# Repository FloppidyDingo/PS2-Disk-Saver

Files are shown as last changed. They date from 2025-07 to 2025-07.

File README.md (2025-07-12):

# PS2-Disk-Saver

A PS2 Slim mod that fixes an issue where the laser ribbon peels up and scratches your disks

If you are printing from this source, you will need to print one of Laser Guard.stl and one of either Ribbon_Shield_V5.stl or Ribbon_Shield_V5_Screw.stl

Installation instructions here: https://github.com/FloppidyDingo/PS2-Disk-Saver/wiki/Installation-Instructions

You can buy premade kits here: https://www.etsy.com/listing/1260716684/playstation-2-disk-saver-ribbon-shield

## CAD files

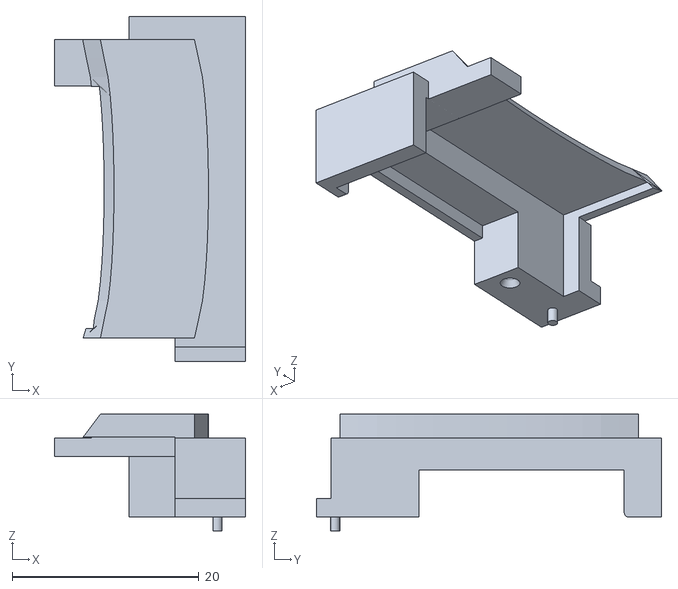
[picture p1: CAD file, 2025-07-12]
PS2 Laser guard.stl
20.5 x 37.0 x 12.5

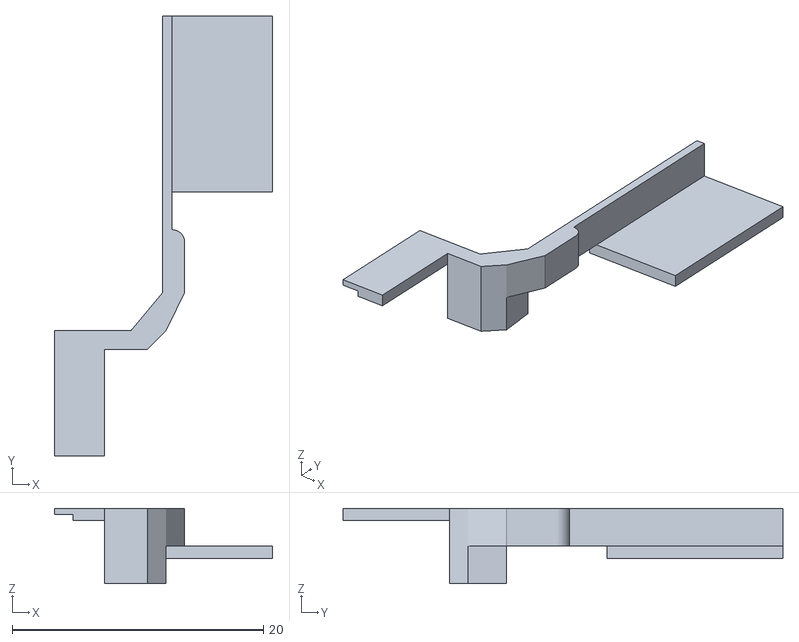
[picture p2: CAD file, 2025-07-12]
PS2 laser ribbon shield V5.stl
17.4 x 35.0 x 6.00

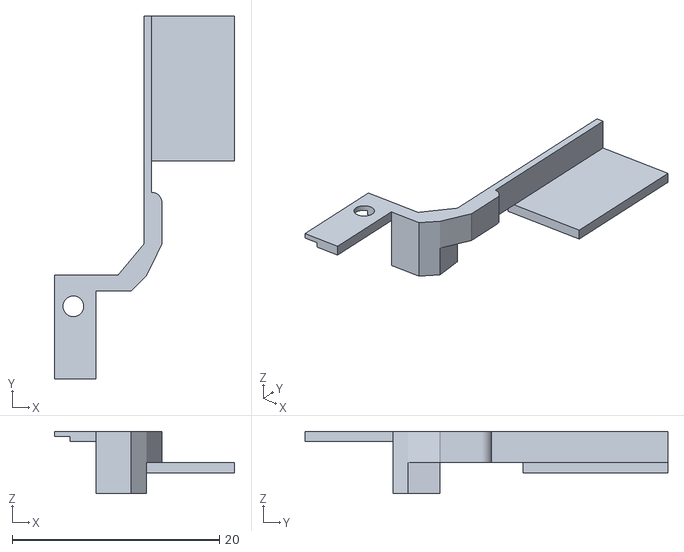
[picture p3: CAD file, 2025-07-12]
PS2 laser ribbon shield V5 Screw.stl
17.4 x 35.0 x 6.00

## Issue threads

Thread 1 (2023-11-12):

Why does the stock cover need to be replaced?

jdfr228, 2023-11-12:
I assume I'm just missing something since I doubt it would be made if it wasn't needed, but what's wrong with the stock cover once the flag/guard piece is installed?  It doesn't seem to be obstructing anything but I must be wrong.  Maybe some light trimming of the original could be done to make it fit as well if there is an issue?  My replacement does not fit very well and I couldn't get the screw to thread all the way into it.

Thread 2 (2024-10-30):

Screw hole version can scratch top shell

jekkkk, 2024-10-30:
I printed this myself (resin) and installed it with the screwed version but the laser assembly kept buzzing when moving and had a ton of resistance. I just noticed that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 was scratching the top shell because it is slightly raised. No idea how to fix the print but I personally ended up making a cutout for the screw in the shell.

FloppidyDingo, 2024-10-30:
Hello! This is something already known with the mod and unfortunately there isn't much I can do about that. The screws I include with the kit have a head height of 0.5mm, there isn't much room after that for thicker screw heads without touching the top shell. Your fix of cutting a slot for the screw is one workaround for that

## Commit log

2022-08-24 add STL files
    [PS2 Laser guard.stl, PS2_Ribbon_Shield_V1.stl]
2023-01-20 Create PS2_Ribbon_Shield_V2_No_Screw.stl
    Screw hole has been removed for stronger glue only installs
    [PS2_Ribbon_Shield_V2_No_Screw.stl]
2024-03-21 Create PS2_Ribbon_Shield_V3.stl
    Larger mounting tab to make it stronger
    [PS2_Ribbon_Shield_V3.stl]
2024-03-21 Update PS2 Laser guard.stl
    Added a bevel to the mounting screw to make it easier to thread the screw in
    [PS2 Laser guard.stl]
2024-07-31 Size adjustment
    Adjusted cable retainer size for better fitment
    [PS2_Ribbon_Shield_V1.stl, PS2_Ribbon_Shield_V2_No_Screw.stl, PS2_Ribbon_Shield_V3.stl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]
2024-08-02 Fixed mistake in exporting STL
    [PS2_Ribbon_Shield_V4.stl, PS2_Ribbon_Shield_V4_Screw.stl]
2025-05-31 Update README.md
    Added instructions for self printing
2025-07-12 Updated design
    Updated design to address some fitment issues in certain models
    [PS2 Laser guard.stl, PS2 laser ribbon shield V5 Screw.stl, PS2 laser ribbon shield V5.stl]
2025-07-12 Delete PS2_Ribbon_Shield_V4.stl
    Remove old design
    [PS2_Ribbon_Shield_V4.stl]
2025-07-12 Delete PS2_Ribbon_Shield_V4_Screw.stl
    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
    [PS2_Ribbon_Shield_V4_Screw.stl]
